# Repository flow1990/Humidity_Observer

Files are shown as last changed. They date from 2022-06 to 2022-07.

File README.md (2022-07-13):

<body>
  <h1># Humidity_Observer</h1>
  <hr>I wanted to have the Voron-Style on my drybox so this idea came up. Case to place a humidity sensor in a storage box and keep the box sealed from air and humidity.
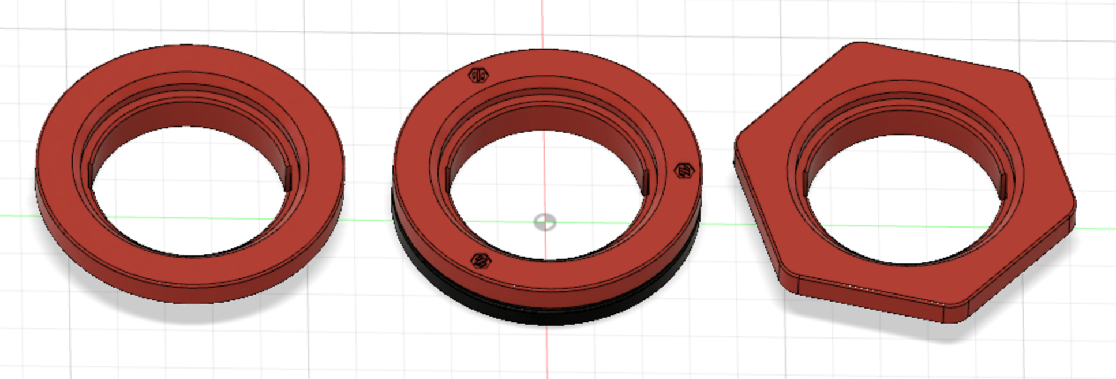
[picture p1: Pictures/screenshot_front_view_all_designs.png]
all_three_designs
  
  <br>All parts except the seal are printed in <B>ABS</B> (esun ABS+ following the Voron print guidelines - 40% infill) the seal is printed in <B>TPU</B> (Bavaria Filaments TPU98). I recommend printing the (a)_outter_thermo_case upside down, in my case no supprt was needed.
  </div>
<div>
  <hr>
  The Hygrometer has to be pressed hard in the case, that's why I recommend not printing in PLA, the case could break while doing this. You have to drill or cut a 45mm circle plus four 3mm holes in your box to fit the whole thing (you can use the drill_stencil.stl for this).
  </div>
  <hr>
  <h2>Installation Guide</h2>
  <dl>
    <dt align="left">Step one</dt>
    <dt align="left">step_one</dt>
    <dd align="left" width="250">Insert the four heat inserts in the <I>(a)_outter_thermo_case.stl</I>.</dd>
    <dd align="left" width="250">Press the Hygrometer in the case.</dd>
    <dt align="right">Step two</dt>
    <dt align="right">step_one</dt>
    <dd align="right" width="250">Place the <I>drill_stencil.stl</I> on the box and secure it with the tape.</dd>
    <dd align="right" width="250">Drill <B>only(!)</B> the hole 45mm hole in the center of the stencil.</dd>
    <dt align="left">Step three</dt>
    <dt align="left">step_one</dt>
    <dd align="left" width="250">With the M3 x 6mm BHCS screw the stencil and the case together.</dd>
    <dt align="right">Step four</dt>
    <dt align="right">step_one</dt>
    <dd align="right" width="250">Place the hole thing in the hole and turn it till the LCD is oriented right.</dd>
    <dd align="right" width="250">With the chalk, make a line like shown in the picture.</dd>
    <dt align="left">Step five</dt>
    <dt align="left">step_one</dt>
    <dd align="left" width="250">Unscrew the stencil from the case again.</dd>
    <dd align="left" width="250">Align the stencil with the hole from step two and the chalkline.</dd>
    <dd align="left" width="250">Drill the holes with a 4mm drill.</dd>
    <dt align="right">Step six</dt>
    <dt align="right">step_one</dt>
    <dd align="right" width="250">Remove the stencil, you won't need it anymore.</dd>
    <dd align="right" width="250">Place the <I>inner_thermo_case.stl</I> inside the box and insert the M3 x 8 SHCS (head of the screws inside the box).   </dd>
    <dt align="left">Step seven</dt>
    <dt align="left">step_one</dt>
    <dd align="left" width="250"></dd>
    <dd align="left" width="250">Place the <I>tpu_seal.stl</I> on the screws (outside of the box).</dd>
    <dd align="left" width="250">Now you can place the case in the holw and screw everything together.</dd>
    <dt align="right" width="250">Done!</dt>
    <dt align="right">step_one</dt>
  </dl>
      <hr>
  <div>
  <dl>
    <dt>Bill of materials</dt>
    <dd>Filament of your choice (I recommend ABS 'cause PLA could break while pressing the hygrometer in)</dd>
    <dd>TPU or other flexibla Filament for the seal</dd>
    <dd>The storage box of your choice (I use the 22l IKEA Samla box which perfectly stores 4 rolls of filament)
    <dd>4 x Heat Insert M3 x D5.0 x L4.0 (aliexpress: https://a.aliexpress.com/_mNUmqR0)</dd>
    <dd>1 x 2In1 Thermometer Hygrometer Mini LCD (aliexpress: https://a.aliexpress.com/_ms3GsKA)</dd>
    <dd>4 x M3 x 8mm SHCS (depends on thickness of your box walls)</dd>
    <br>
    <dt>Needed for installation</dt>
    <dd>2-4 x M3 x 6mm BHCS</dd>
    <dd>A piece of wood</dd>
    <dd>Duct tape</dd>
    <dd>Chalk</dd>
  </dl>
  </div>
</body>

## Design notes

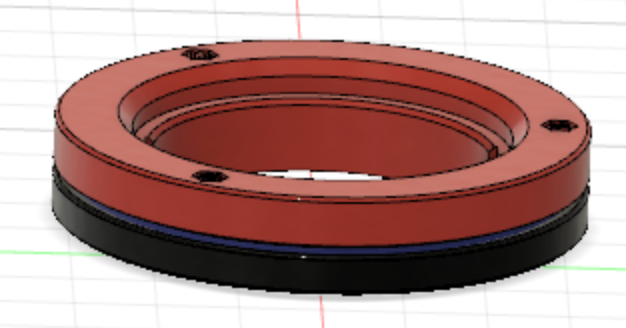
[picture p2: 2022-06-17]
Pictures/screenshot_side_view_voron_design.png

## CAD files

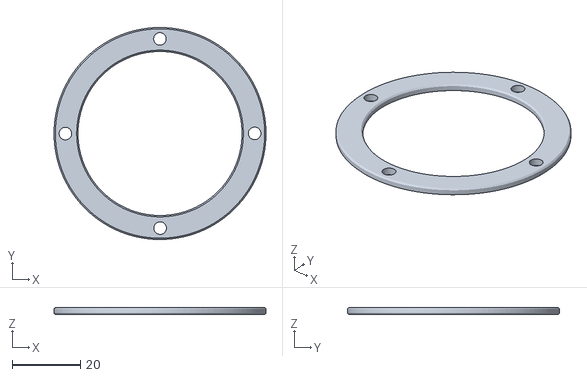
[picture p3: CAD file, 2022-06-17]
STLs/tpu_seal.stl
62.2 x 62.2 x 2.00

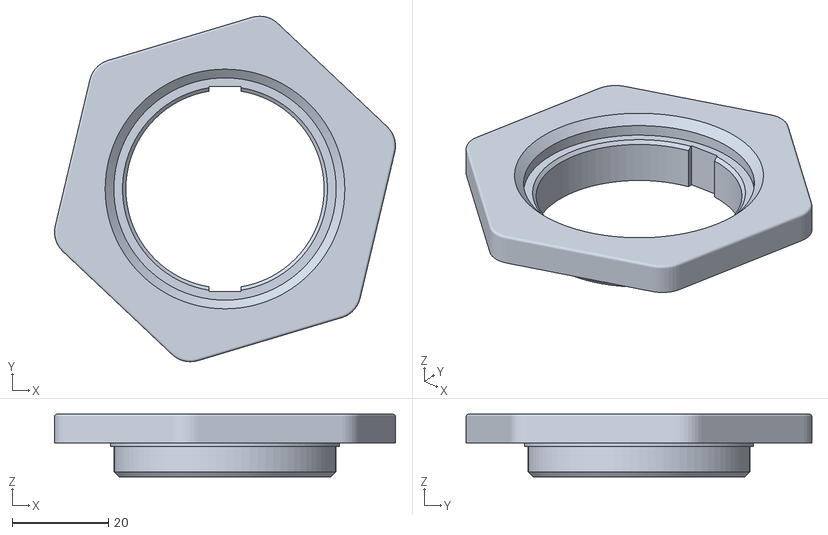
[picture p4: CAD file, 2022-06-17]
STLs/(a)_outter_thermo_casevoron_design.stl
70.7 x 71.7 x 13.0

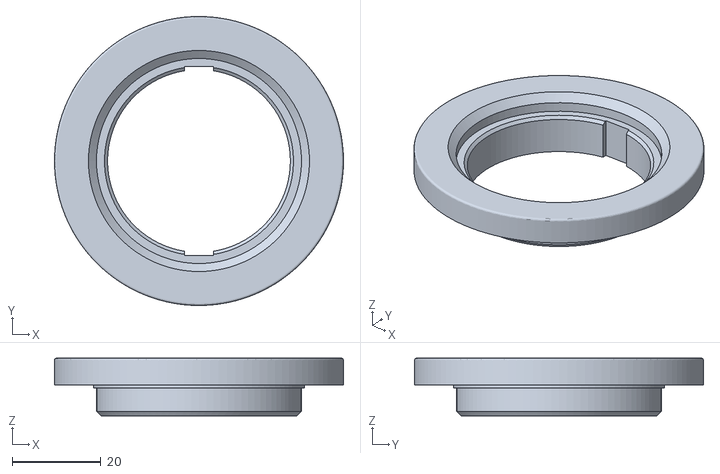
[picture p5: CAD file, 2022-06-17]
STLs/(a)_outter_thermo_case.stl
65.0 x 65.0 x 13.0

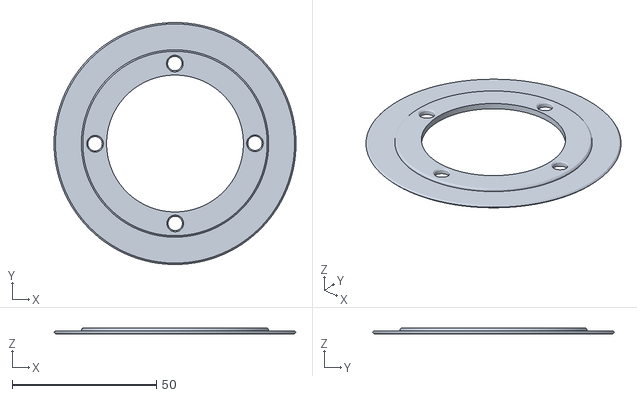
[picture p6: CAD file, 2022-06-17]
STLs/drill_stencil.stl
84.0 x 84.0 x 2.00

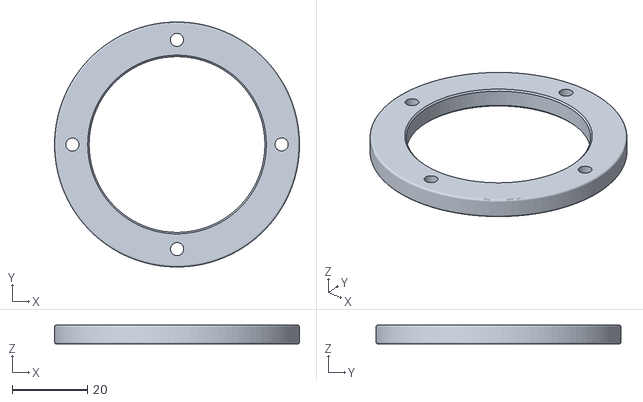
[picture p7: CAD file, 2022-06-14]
STLs/inner_thermo_case.stl
65.0 x 65.0 x 5.00

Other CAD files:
STLs/(a)_outter_thermo_case_voron_logo.stl

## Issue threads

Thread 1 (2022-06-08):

shcs holes too big

flow1990, 2022-06-08:
smaller the size of the holes for the head shcs screw from 7.5mm to 6mm.

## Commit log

2022-06-08 stl files uploaded
    [(a)_outter_thermo_case_v2.2.stl, inner_thermo_case_v1.2.stl, tpu_seal_v1.stl]
2022-06-08 all versions
    [(a)_outter_thermo_case_v2.1.stl, (a)_outter_thermo_case_v2.2.stl, (a)_outter_thermo_case_v2.stl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]
2022-06-08 STLs and CAD folder uploaded
2022-06-08 files uploaded
    [(a)_outter_thermo_case_voron_logo.stl, inner_thermo_case.stl, thermo_case v5.f3d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]
2022-06-08 CAD file uploaded
    [humidity_observer.f3d]
2022-06-08 BOM included
2022-06-08 other designs uploaded
    [(a)_outter_thermo_case.stl, (a)_outter_thermo_casevoron_design.stl, humidity_observer.f3d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]
2022-06-09 new designs added
    [(a)_outter_thermo_case.stl, (a)_outter_thermo_casevoron_design.stl, tpu_seal.stl]
2022-06-09 some issues fixed
    [(a)_outter_thermo_case_voron_logo.stl, inner_thermo_case.stl, tpu_seal.stl]
2022-06-09 issues solved
    [(a)_outter_thermo_case.stl, (a)_outter_thermo_case_voron_logo.stl, (a)_outter_thermo_casevoron_design.stl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]
2022-06-13 files updated
    [(a)_outter_thermo_case.stl, (a)_outter_thermo_case_voron_logo.stl, (a)_outter_thermo_casevoron_design.stl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]
2022-06-13 updated stl files
    [(a)_outter_thermo_case.stl, (a)_outter_thermo_case_voron_logo.stl, (a)_outter_thermo_casevoron_design.stl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]
2022-06-14 issue solved
    [inner_thermo_case.stl]
2022-06-17 pictures for installation guide added
    [(a)_outter_thermo_case.stl, (a)_outter_thermo_case_voron_logo.stl, (a)_outter_thermo_casevoron_design.stl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]
2022-06-17 seal updated
    [tpu_seal.stl]
